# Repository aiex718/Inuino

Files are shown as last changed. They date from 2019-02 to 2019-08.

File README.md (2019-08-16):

# Inuino
An Arduino Uno compatible microcontroller dev board based on the ATmega644P / ATmega1284P, using official core inside Arduino IDE.

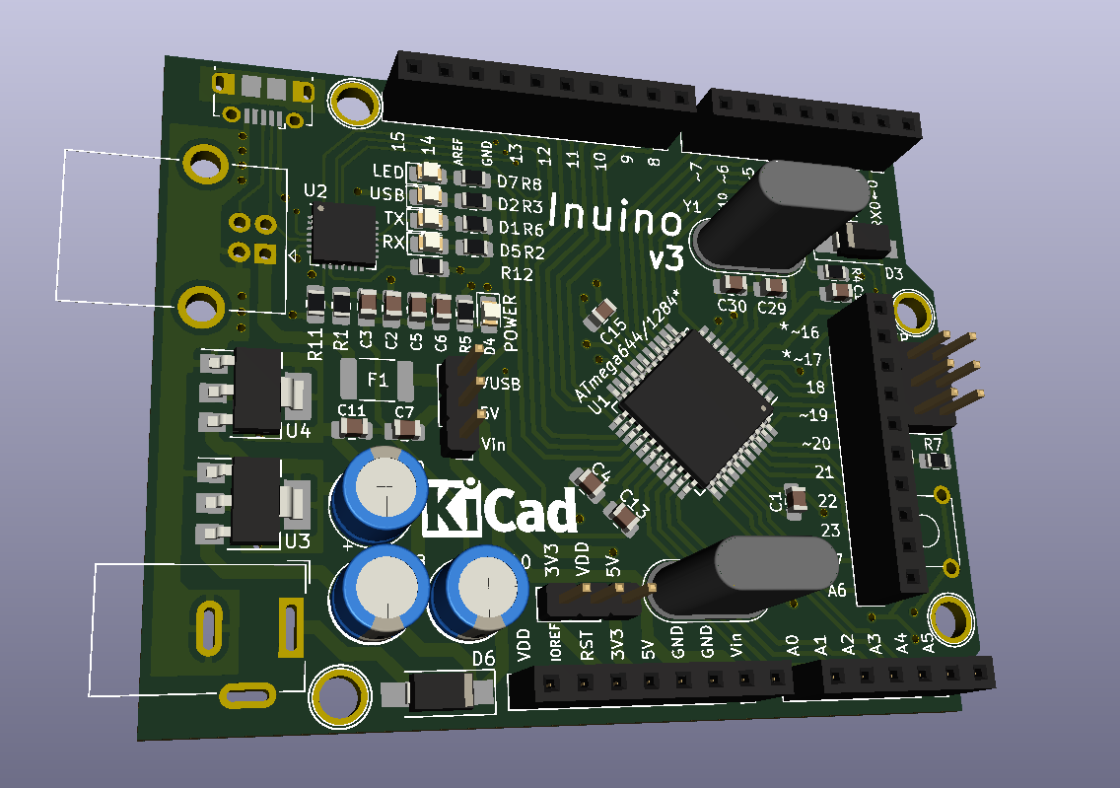
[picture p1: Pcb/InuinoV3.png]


# Usage
Add this link to boards manager

<https://raw.githubusercontent.com/aiex718/Inuino/master/Release/package_inuino_index.json>

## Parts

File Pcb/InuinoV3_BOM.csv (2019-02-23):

Id | Designator | Package | Quantity | Designation | Supplier and ref
1 | REF** | KiCad-Logo_5mm_SilkScreen | 1 | KiCad-Logo_5mm_SilkScreen
2 | J11 | PinHeader_1x03_P2.54mm_Vertical | 1 | VBUS_Jmp
3 | J10 | PinHeader_1x03_P2.54mm_Vertical | 1 | VDD_Jmp
4 | SW1 | SW_TH_Tactile_Omron_B3F-10xx | 1 | SW_DIP_x02
5 | C5,C1,C2,C4,C12,C13,C14,C15 | C_0805_2012Metric_Pad1.15x1.40mm_HandSolder | 8 | 100n
6 | U2 | QFN-28-1EP_5x5mm_P0.5mm_EP3.35x3.35mm_ThermalVias | 1 | CP2102N-A01-GQFN28
7 | R12,R2,R3,R5,R6,R7 | R_0805_2012Metric_Pad1.15x1.40mm_HandSolder | 6 | 1K
8 | R11 | R_0805_2012Metric_Pad1.15x1.40mm_HandSolder | 1 | 47.5K
9 | R10 | R_0805_2012Metric_Pad1.15x1.40mm_HandSolder | 1 | 1M
10 | D4 | LED_0805_2012Metric_Pad1.15x1.40mm_HandSolder | 1 | POWER
11 | D3 | D_SMA_Handsoldering | 1 | 1N5819
12 | J8 | PinSocket_1x10_P2.54mm_Vertical | 1 | IO3
13 | Y1 | Crystal_HC49-U_Vertical | 1 | 16M
14 | P5,P6,P7,P8 | Arduino_1pin | 4 | CONN_01X01
15 | C3,C6 | C_0805_2012Metric_Pad1.15x1.40mm_HandSolder | 2 | 4.7uF
16 | C7,C11 | C_0805_2012Metric_Pad1.15x1.40mm_HandSolder | 2 | 1uF
17 | C8,C9,C10 | CP_Radial_D6.3mm_P2.50mm | 3 | 47uF
18 | C29,C30 | C_0805_2012Metric_Pad1.15x1.40mm_HandSolder | 2 | 22p
19 | D1 | LED_0805_2012Metric_Pad1.15x1.40mm_HandSolder | 1 | RXD
20 | D2 | LED_0805_2012Metric_Pad1.15x1.40mm_HandSolder | 1 | USB_CONN
21 | D5 | LED_0805_2012Metric_Pad1.15x1.40mm_HandSolder | 1 | TXD
22 | D6 | D_SMA_Handsoldering | 1 | SM4007
23 | F1 | Fuse_1812_4532Metric_Pad1.30x3.40mm_HandSolder | 1 | 500mA
24 | J1 | PinHeader_2x03_P2.54mm_Vertical | 1 | ICSP
25 | J2 | USB_Micro-B_Molex-105017-0001 | 1 | USB_B_Micro
26 | J3 | PinSocket_1x10_P2.54mm_Vertical | 1 | IO1
27 | J4 | PinSocket_1x08_P2.54mm_Vertical | 1 | POWER_CONN
28 | J5 | USB_B_OST_USB-B1HSxx_Horizontal | 1 | USB_B
29 | J6 | PinSocket_1x08_P2.54mm_Vertical | 1 | IO0
30 | J7 | PinSocket_1x06_P2.54mm_Vertical | 1 | IO2
31 | J9 | BarrelJack_Wuerth_6941xx301002 | 1 | Jack-DC
32 | R1 | R_0805_2012Metric_Pad1.15x1.40mm_HandSolder | 1 | 22.1K
33 | R4,R8 | R_0805_2012Metric_Pad1.15x1.40mm_HandSolder | 2 | 300
34 | U3 | SOT-223-3_TabPin2 | 1 | AMS1117-5.0
35 | U4 | SOT-223-3_TabPin2 | 1 | AMS1117-3.3
36 | Y2 | Crystal_HC49-U_Vertical | 1 | 8M
37 | U1 | LQFP-44_10x10mm_P0.8mm | 1 | IC--ATMEGA644PA-AU
38 | D7 | LED_0805_2012Metric_Pad1.15x1.40mm_HandSolder | 1 | LED

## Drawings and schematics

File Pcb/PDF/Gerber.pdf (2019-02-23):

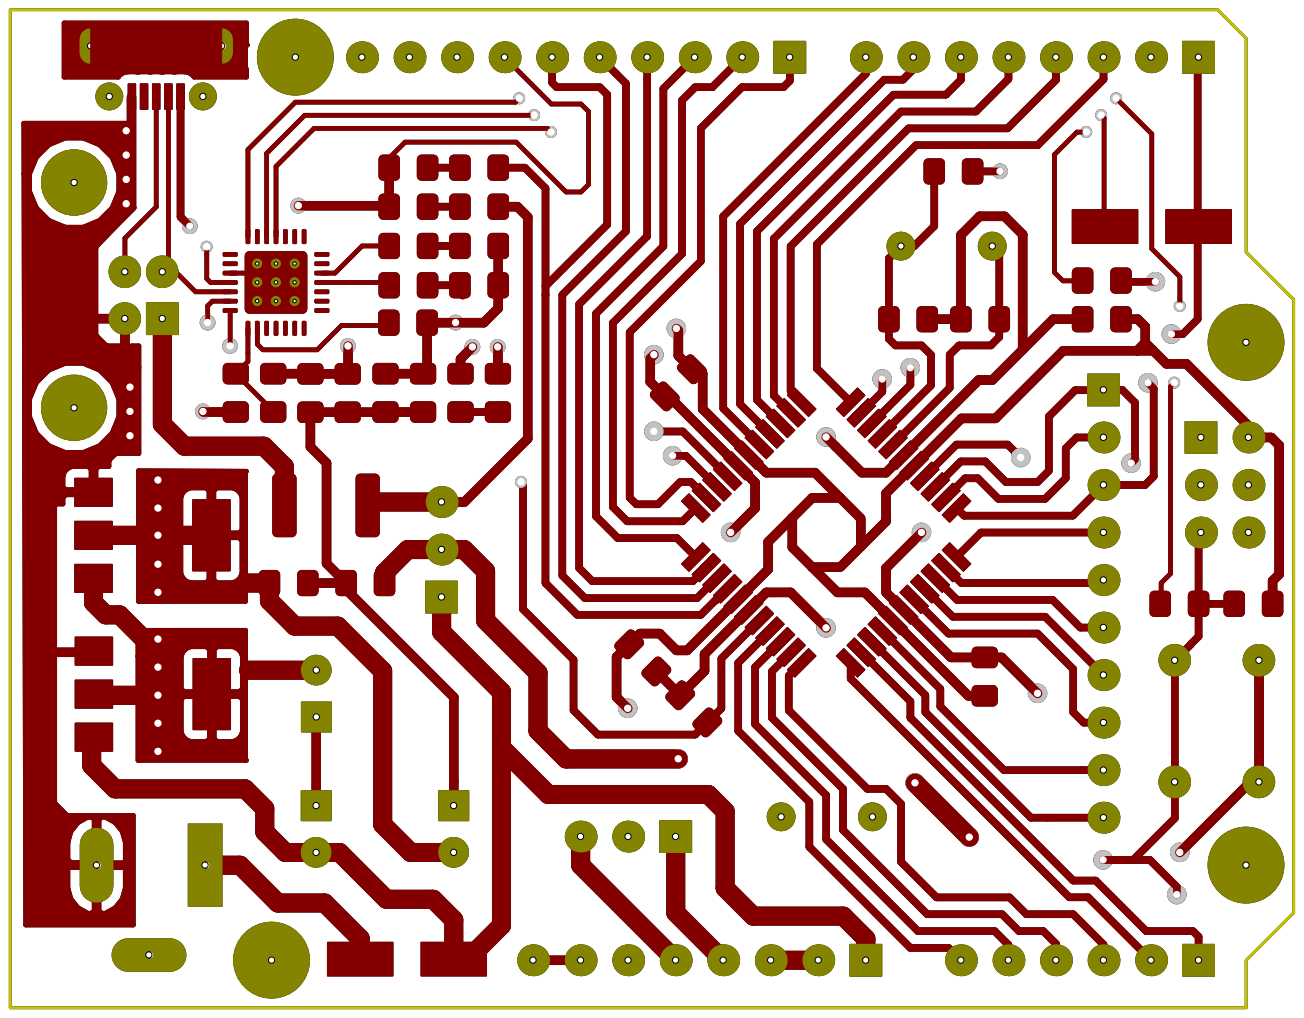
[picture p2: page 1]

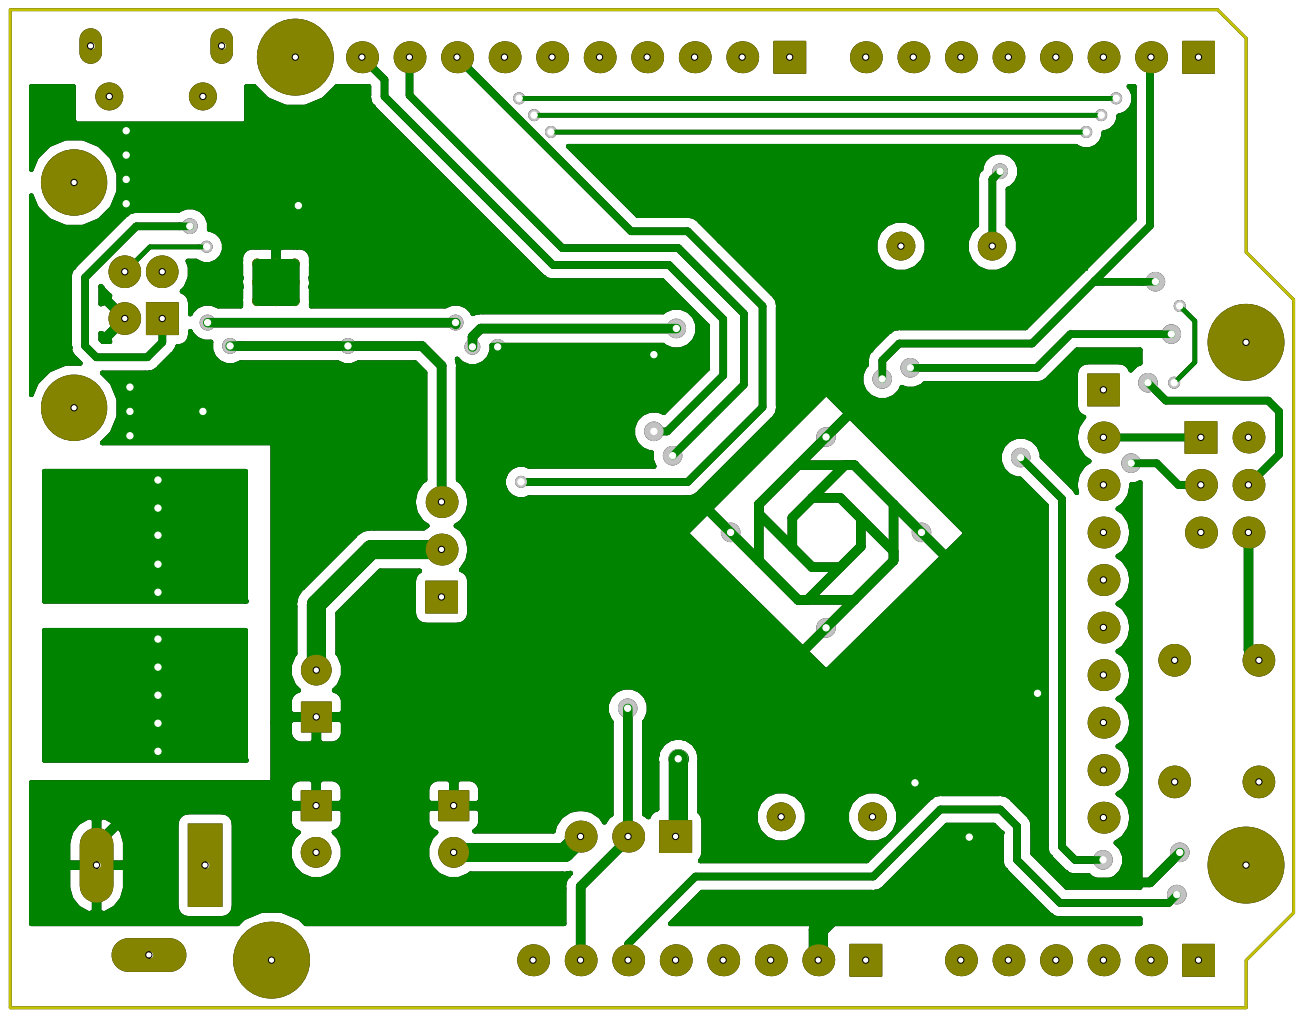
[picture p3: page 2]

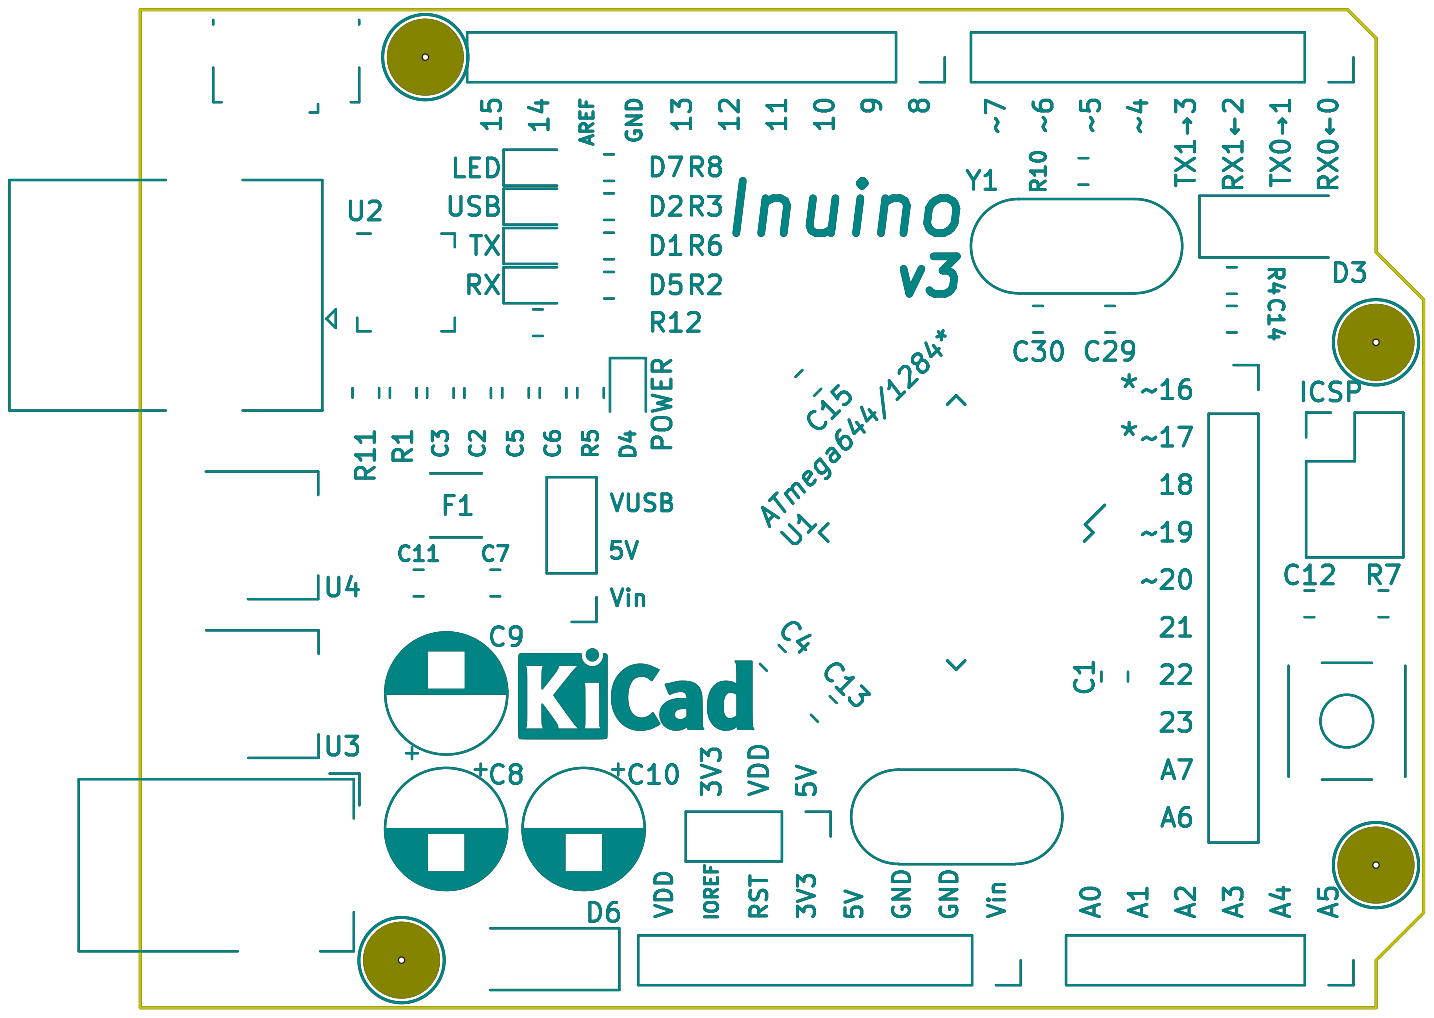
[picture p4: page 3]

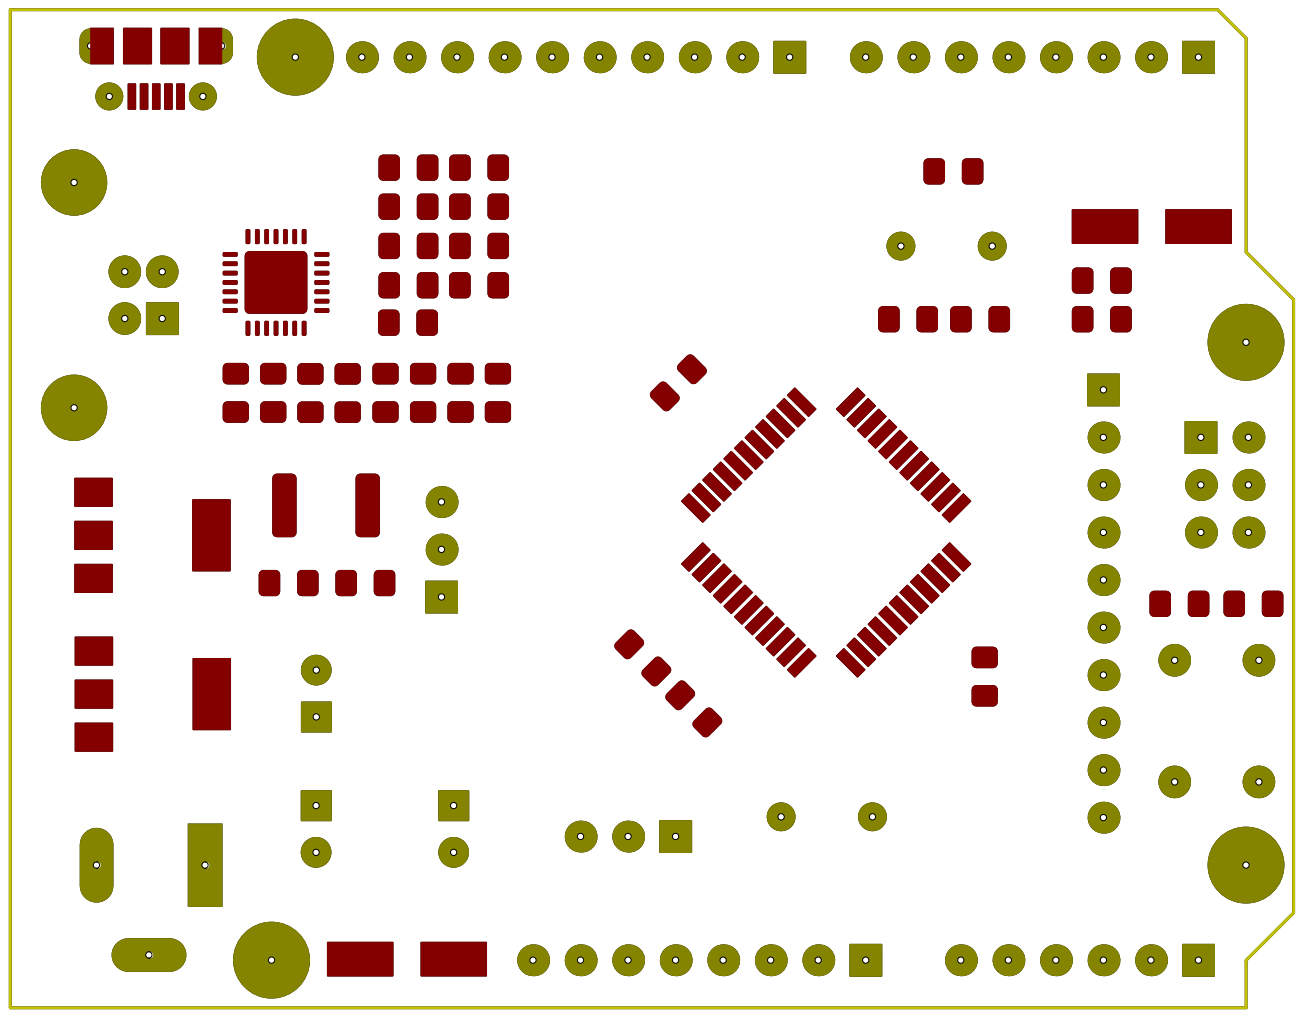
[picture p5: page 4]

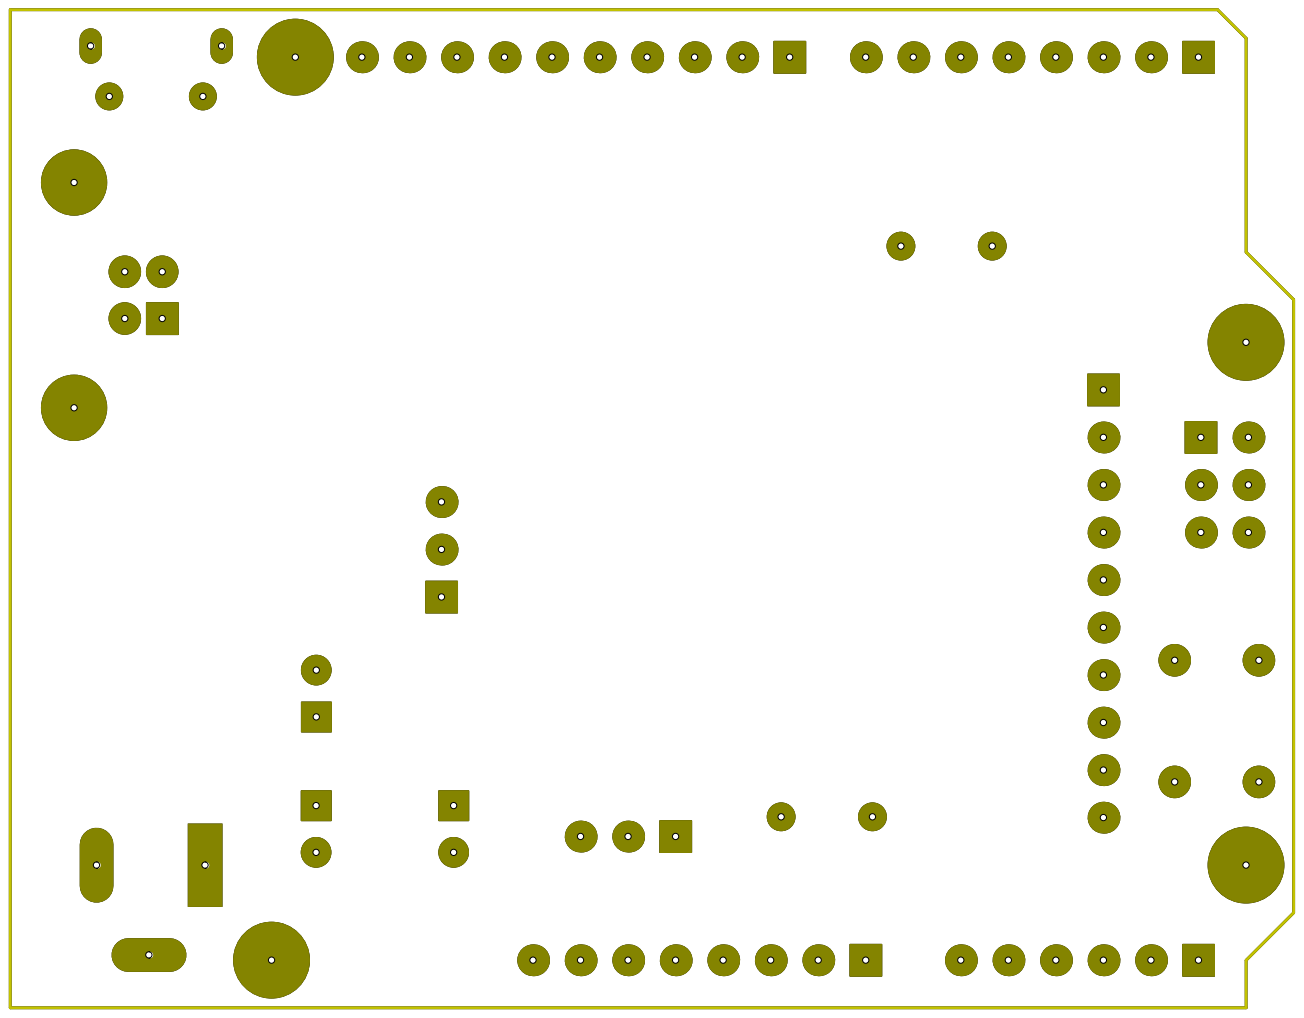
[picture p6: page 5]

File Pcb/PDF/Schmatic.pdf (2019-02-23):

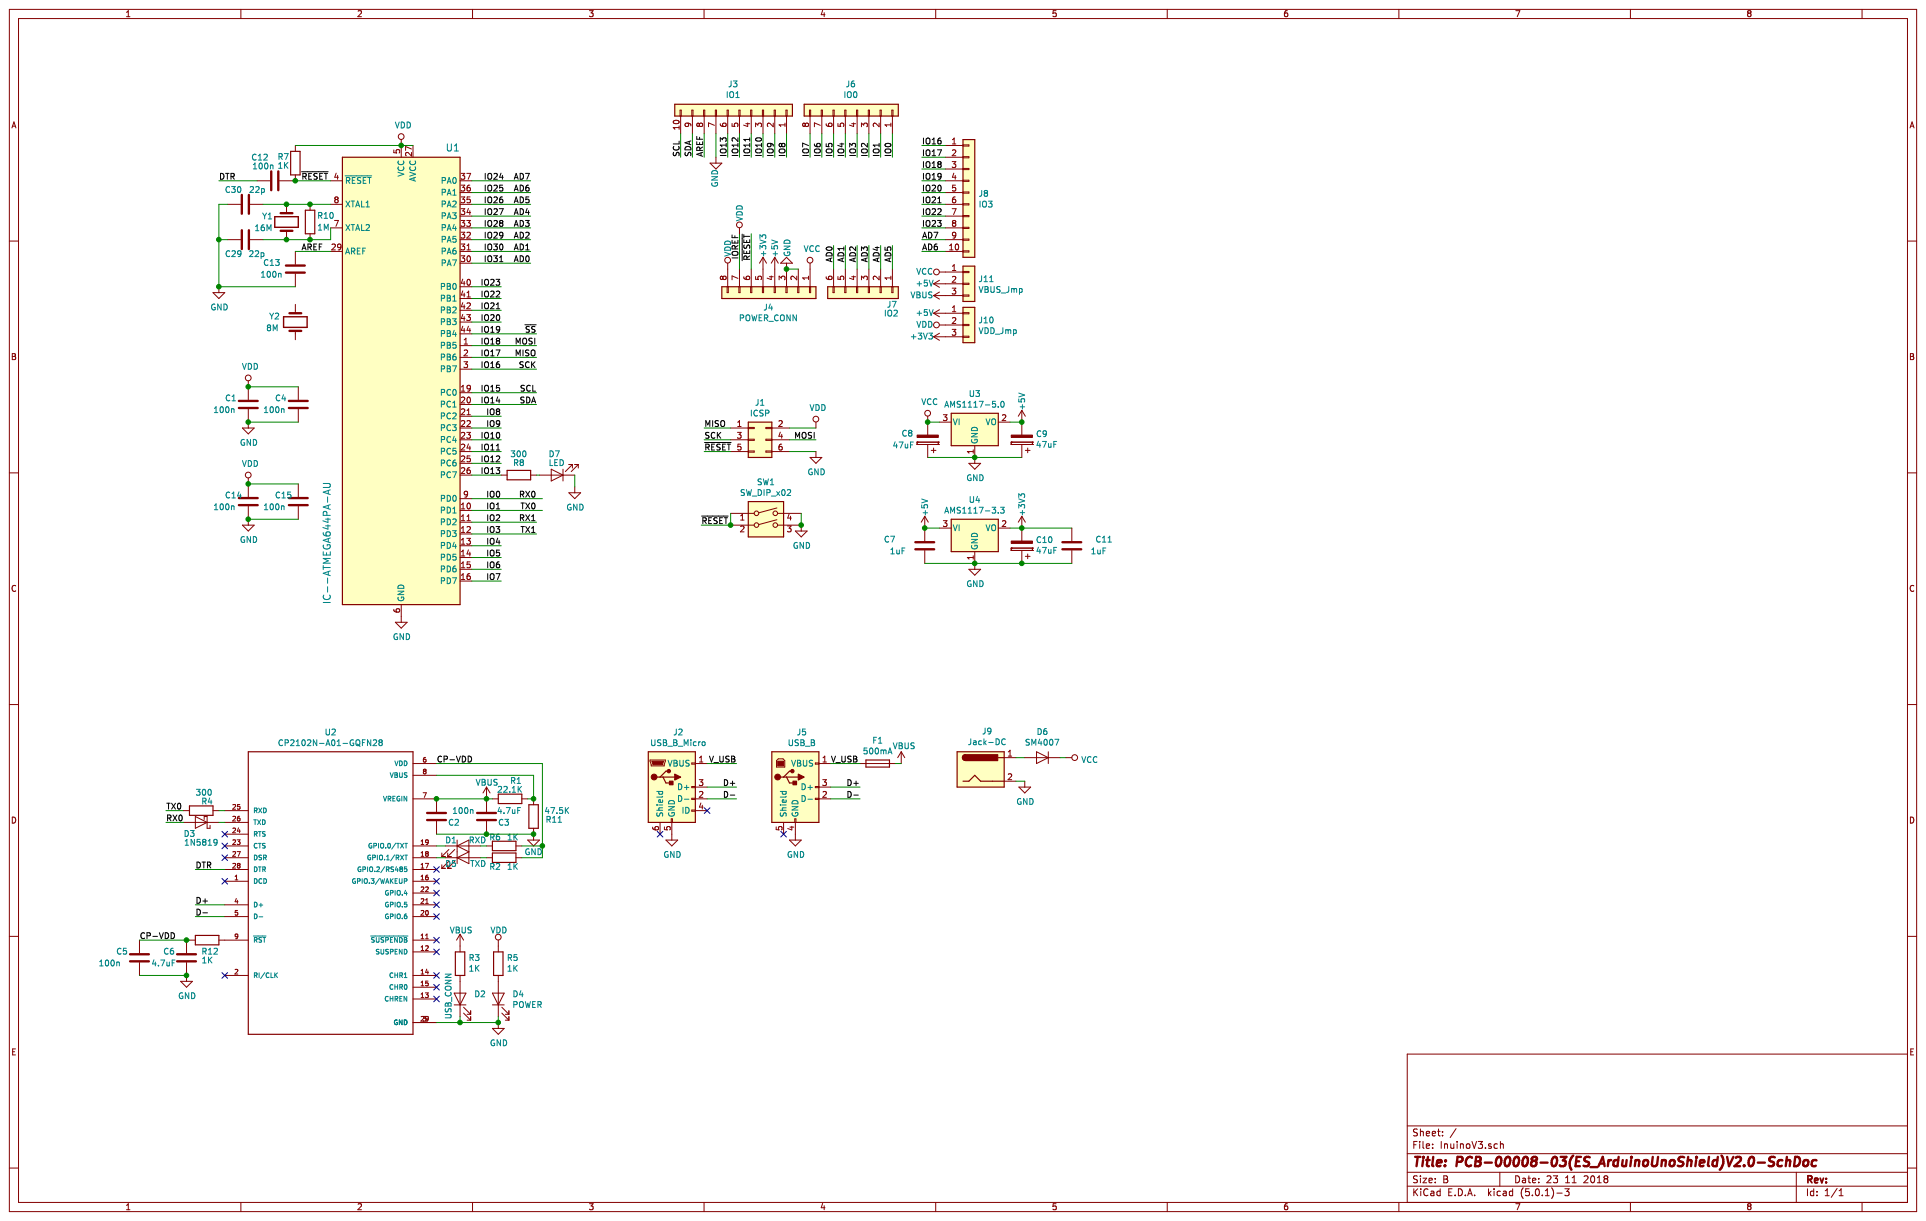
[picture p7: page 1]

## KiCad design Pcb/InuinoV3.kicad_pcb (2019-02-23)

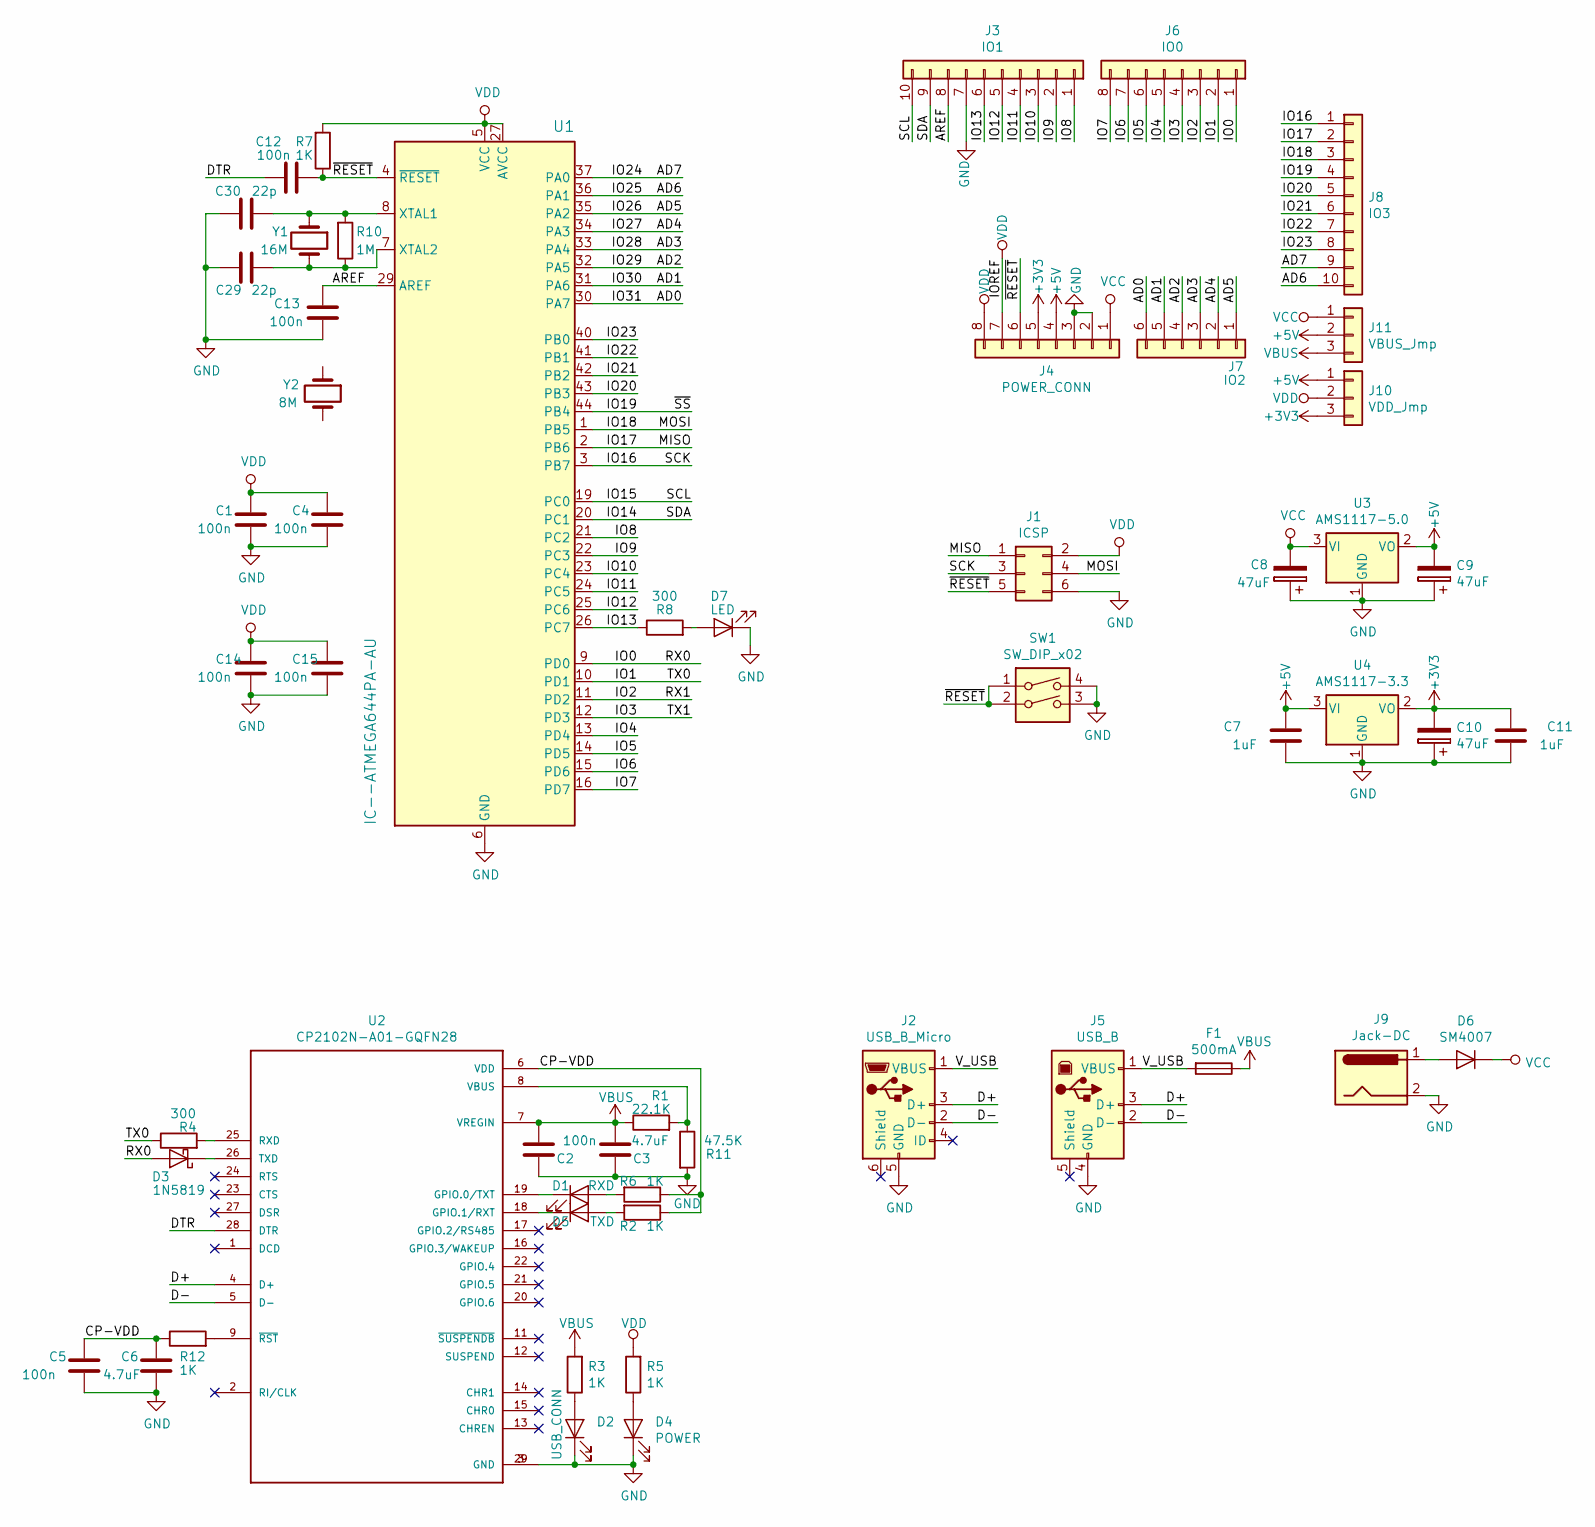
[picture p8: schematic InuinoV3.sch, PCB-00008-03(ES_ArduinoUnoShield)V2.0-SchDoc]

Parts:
C1, C2, C4, C5, C12, C13, C14, C15: 100n; C_0805_2012Metric_Pad1.15x1.40mm_HandSolder
C3, C6: 4.7uF; C_0805_2012Metric_Pad1.15x1.40mm_HandSolder
C7, C11: 1uF; C_0805_2012Metric_Pad1.15x1.40mm_HandSolder
C8, C9, C10: 47uF; CP_Radial_D6.3mm_P2.50mm
C29, C30: 22p; C_0805_2012Metric_Pad1.15x1.40mm_HandSolder
D1: RXD; LED_0805_2012Metric_Pad1.15x1.40mm_HandSolder
D2: USB_CONN; LED_0805_2012Metric_Pad1.15x1.40mm_HandSolder
D3: 1N5819; D_SMA_Handsoldering
D4: POWER; LED_0805_2012Metric_Pad1.15x1.40mm_HandSolder
D5: TXD; LED_0805_2012Metric_Pad1.15x1.40mm_HandSolder
D6: SM4007; D_SMA_Handsoldering
D7: LED; LED_0805_2012Metric_Pad1.15x1.40mm_HandSolder
F1: 500mA; Fuse_1812_4532Metric_Pad1.30x3.40mm_HandSolder
J1: ICSP; PinHeader_2x03_P2.54mm_Vertical
J2: USB_B_Micro; USB_Micro-B_Molex-105017-0001
J3: IO1; PinSocket_1x10_P2.54mm_Vertical
J4: POWER_CONN; PinSocket_1x08_P2.54mm_Vertical
J5: USB_B; USB_B_OST_USB-B1HSxx_Horizontal
J6: IO0; PinSocket_1x08_P2.54mm_Vertical
J7: IO2; PinSocket_1x06_P2.54mm_Vertical
J8: IO3; PinSocket_1x10_P2.54mm_Vertical
J9: Jack-DC; BarrelJack_Wuerth_6941xx301002
J10: VDD_Jmp; PinHeader_1x03_P2.54mm_Vertical
J11: VBUS_Jmp; PinHeader_1x03_P2.54mm_Vertical
R1: 22.1K; R_0805_2012Metric_Pad1.15x1.40mm_HandSolder
R2, R3, R5, R6, R7, R12: 1K; R_0805_2012Metric_Pad1.15x1.40mm_HandSolder
R4, R8: 300; R_0805_2012Metric_Pad1.15x1.40mm_HandSolder
R10: 1M; R_0805_2012Metric_Pad1.15x1.40mm_HandSolder
R11: 47.5K; R_0805_2012Metric_Pad1.15x1.40mm_HandSolder
SW1: SW_DIP_x02; SW_TH_Tactile_Omron_B3F-10xx
U1: IC--ATMEGA644PA-AU; LQFP-44_10x10mm_P0.8mm
U2: CP2102N-A01-GQFN28; QFN-28-1EP_5x5mm_P0.5mm_EP3.35x3.35mm_ThermalVias
U3: AMS1117-5.0; SOT-223-3_TabPin2
U4: AMS1117-3.3; SOT-223-3_TabPin2
Y1: 16M; Crystal_HC49-U_Vertical
Y2: 8M; Crystal_HC49-U_Vertical

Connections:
+3V3: C10.2, C11.2, J4.5, J10.3, U4.2 (VO)
+5V: C7.2, C9.2, J4.4, J10.1, J11.2, U3.2 (VO), U4.3 (VI)
/AD0: J7.6, U1.30 (PA7)
/AD1: J7.5, U1.31 (PA6)
/AD2: J7.4, U1.32 (PA5)
/AD3: J7.3, U1.33 (PA4)
/AD4: J7.2, U1.34 (PA3)
/AD5: J7.1, U1.35 (PA2)
/AD6: J8.10, U1.36 (PA1)
/AD7: J8.9, U1.37 (PA0)
/AREF: C13.2, J3.8, U1.29 (AREF)
/CP-VDD: C5.2, C6.2, R2.1, R6.1, R12.1, U2.6 (VDD)
/D+: J2.3 (D+), J5.3 (D+), U2.4 (D+)
/D-: J2.2 (D-), J5.2 (D-), U2.5 (D-)
/DTR: C12.2, U2.28 (DTR)
/IO0: D3.2 (A), J6.1, U1.9 (PD0)
/IO1: J6.2, R4.1, U1.10 (PD1)
/IO2: J6.3, U1.11 (PD2)
/IO3: J6.4, U1.12 (PD3)
/IO4: J6.5, U1.13 (PD4)
/IO5: J6.6, U1.14 (PD5)
/IO6: J6.7, U1.15 (PD6)
/IO7: J6.8, U1.16 (PD7)
/IO8: J3.1, U1.21 (PC2)
/IO9: J3.2, U1.22 (PC3)
/IO10: J3.3, U1.23 (PC4)
/IO11: J3.4, U1.24 (PC5)
/IO12: J3.5, U1.25 (PC6)
/IO13: J3.6, R8.1, U1.26 (PC7)
/IO14: J3.9, U1.20 (PC1)
/IO15: J3.10, U1.19 (PC0)
/IO16: J1.3, J8.1, U1.3 (PB7)
/IO17: J1.1, J8.2, U1.2 (PB6)
/IO18: J1.4, J8.3, U1.1 (PB5)
/IO19: J8.4, U1.44 (PB4)
/IO20: J8.5, U1.43 (PB3)
/IO21: J8.6, U1.42 (PB2)
/IO22: J8.7, U1.41 (PB1)
/IO23: J8.8, U1.40 (PB0)
/V_USB: F1.2, J2.1 (VBUS), J5.1 (VBUS)
/~RESET~: C12.1, J1.5, J4.6, R7.1, SW1.1, SW1.2, U1.4 (~RESET)
GND: C1.1, C2.2, C3.2, C4.1, C5.1, C6.1, C7.1, C8.1, C9.1, C10.1, C11.1, C13.1, C14.1, C15.1, C29.1, C30.2, D2.1 (K), D4.1 (K), D7.1 (K), J1.6, J2.5 (GND), J3.7, J4.2, J4.3, J5.4 (GND), J9.2, R11.2, SW1.3, SW1.4, U1.6 (GND), U1.18 (GND), U1.28 (GND), U1.39 (GND), U2.3 (GND), U2.29 (GND), U3.1 (GND), U4.1 (GND)
unnamed: C29.2, R10.1, U1.7 (XTAL2), Y1.2
unnamed: C30.1, R10.2, U1.8 (XTAL1), Y1.1
unnamed: D1.1 (K), U2.19 (GPIO.0/TXT)
unnamed: D1.2 (A), R6.2
unnamed: D2.2 (A), R3.1
unnamed: D3.1 (K), U2.26 (TXD)
unnamed: D4.2 (A), R5.1
unnamed: D5.1 (K), U2.18 (GPIO.1/RXT)
unnamed: D5.2 (A), R2.2
unnamed: D6.2 (A), J9.1
unnamed: D7.2 (A), R8.2
unnamed: R1.2, R11.1, U2.8 (VBUS)
unnamed: R4.2, U2.25 (RXD)
unnamed: R12.2, U2.9 (~RST~)
VBUS: C2.1, C3.1, F1.1, J11.3, R1.1, R3.2, U2.7 (VREGIN)
VCC: C8.2, D6.1 (K), J4.1, J11.1, U3.3 (VI)
VDD: C1.2, C4.2, C14.2, C15.2, J1.2, J4.7, J4.8, J10.2, R5.2, R7.2, U1.5 (VCC), U1.17 (VCC), U1.27 (AVCC), U1.38 (VCC)

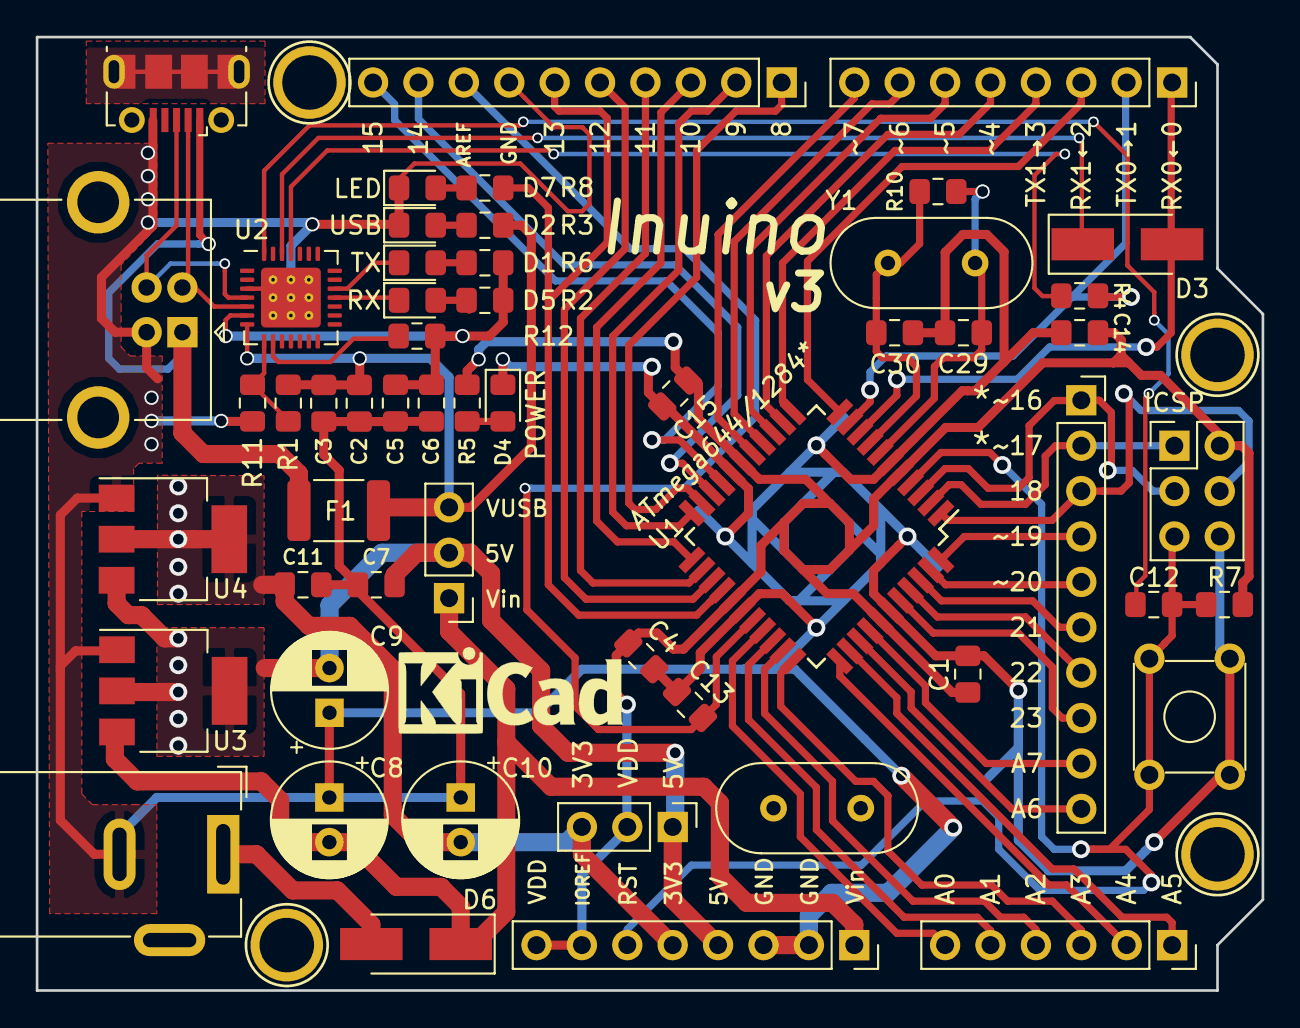
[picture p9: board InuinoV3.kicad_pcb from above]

Board: 2 copper layers, 68.6 x 53.3 mm, 58 parts (0 on the bottom side), 59 nets.

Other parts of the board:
P5, P6, P7, P8: CONN_01X01; Arduino_1pin

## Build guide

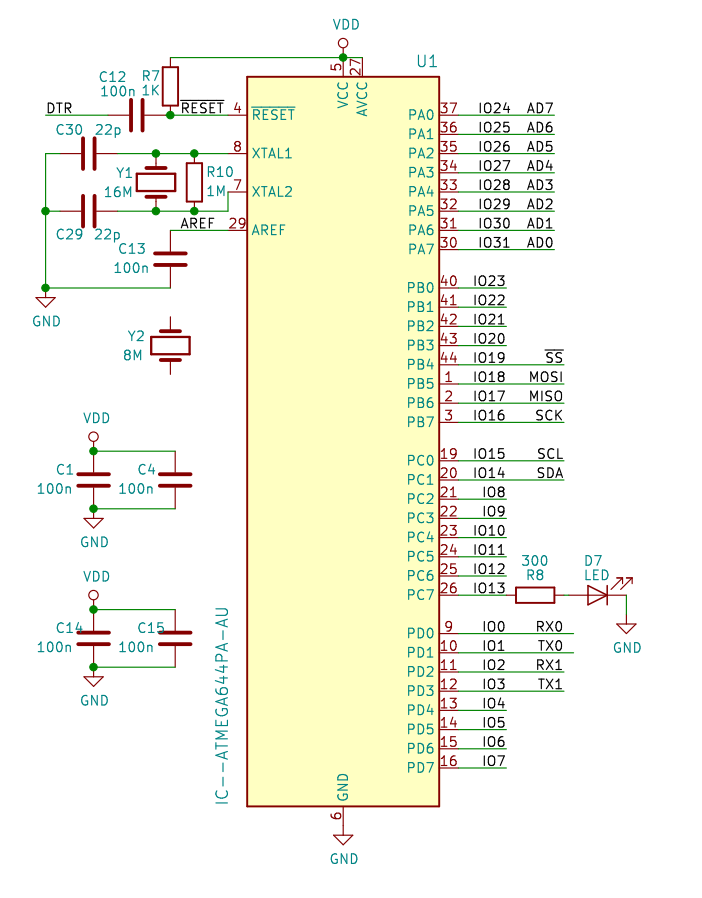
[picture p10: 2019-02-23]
Pcb/Wiring.png

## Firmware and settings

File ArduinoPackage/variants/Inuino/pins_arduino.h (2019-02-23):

/*
  pins_arduino.h - Pin definition functions for Arduino
  Part of Arduino - http://www.arduino.cc/

  Copyright (c) 2007 David A. Mellis

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
  You should have received a copy of the GNU Lesser General
  Public License along with this library; if not, write to the
  Free Software Foundation, Inc., 59 Temple Place, Suite 330,
  Boston, MA  02111-1307  USA
*/

#ifndef Pins_Arduino_h
#define Pins_Arduino_h

#include <avr/pgmspace.h>

#define NUM_DIGITAL_PINS            32
#define NUM_ANALOG_INPUTS           8

//Set SPI and I2C to digital pins
static const uint8_t SS   = 19;
static const uint8_t MOSI = 18;
static const uint8_t MISO = 17;
static const uint8_t SCK  = 16;

static const uint8_t SDA = 14;
static const uint8_t SCL = 15;

//Set LED_BUILTIN to digital pins
#define LED_BUILTIN 13

//Set analog pins to digital pins
static const uint8_t A0 = 31;
static const uint8_t A1 = 30;
static const uint8_t A2 = 29;
static const uint8_t A3 = 28;
static const uint8_t A4 = 27;
static const uint8_t A5 = 26;
static const uint8_t A6 = 25;
static const uint8_t A7 = 24;


//Set analog pins to digital pins, A?=D?
#define analogInputToDigitalPin(p)  ((p < NUM_ANALOG_INPUTS) ? 31 - (p) : -1)



//Set which digital pins has pwm(timer)
#if defined(__AVR_ATmega644P__)
#define digitalPinHasPWM(p)         ((p) == 4 || (p) == 5 || (p) == 6 || (p) == 7 || (p) == 19 || (p) == 20)
#elif defined(__AVR_ATmega1284P__)
#define digitalPinHasPWM(p)         ((p) == 4 || (p) == 5 || (p) == 6 || (p) == 7 || (p) == 16 || (p) == 17 || (p) == 19 || (p) == 20)
#endif


// Set digitalPin To PCICR
// p.s. All digitalPin on 644p/1284p has PCICR
#define digitalPinToPCICR(p)    (((p) >= 0 && (p) < NUM_DIGITAL_PINS) ? (&PCICR) : ((uint8_t *)0)) 

// Set digitalPin To PCICR bit
// PortD = 3,PortC = 2,PortB = 1,PortA = 0
#define digitalPinToPCICRbit(p) (((p) <= 7) ? 3 : (((p) <= 15) ? 2 : (((p) <= 23) ? 1 : 0)))

// Set digitalPin To PCMSK 
// PortD = &PCMSK3,PortC = &PCMSK2,PortB = &PCMSK1,PortA = &PCMSK0
#define digitalPinToPCMSK(p)    (((p) <= 7) ? (&PCMSK3) : (((p) <= 15) ? (&PCMSK2) : (((p) <= 23) ? (&PCMSK1) : (&PCMSK0))))  


// Set digitalPin To PCMSK bit
// Relative to digital_pin_to_port_PGM and digital_pin_to_bit_mask_PGM
#define digitalPinToPCMSKbit(p) (((p) <= 7) ? ((p) % 8) : (((p) <= 13) ? ( (p) - 6 ) : (((p) <= 15) ? ( 15 - (p)) : (((p)<=23)?( 23 - (p) ):((p) % 8))))) 

//Set which digital pins has interrupt
#define digitalPinToInterrupt(p)  ((p) == 2 ? 0 : ((p) == 3 ? 1 : ((p) == 21 ? 2 : NOT_AN_INTERRUPT)))


#ifdef ARDUINO_MAIN


// these arrays map port names (e.g. port B) to the
// appropriate addresses for various functions (e.g. reading
// and writing)
const uint16_t PROGMEM port_to_mode_PGM[] = {
	NOT_A_PORT,
	(uint16_t) &DDRA,
	(uint16_t) &DDRB,
	(uint16_t) &DDRC,
	(uint16_t) &DDRD,
};

const uint16_t PROGMEM port_to_output_PGM[] = {
	NOT_A_PORT,
	(uint16_t) &PORTA,
	(uint16_t) &PORTB,
	(uint16_t) &PORTC,
	(uint16_t) &PORTD,
};

const uint16_t PROGMEM port_to_input_PGM[] = {
	NOT_A_PORT,
	(uint16_t) &PINA,
	(uint16_t) &PINB,
	(uint16_t) &PINC,
	(uint16_t) &PIND,
};

const uint8_t PROGMEM digital_pin_to_port_PGM[] = {
	PD, //D0
	PD,
	PD,
	PD,
	PD,
	PD,
	PD,
	PD,
	PC, //D8
	PC,
	PC,
	PC,
	PC,
	PC,
	PC, 
	PC,
	PB, //D16
	PB,
	PB,
	PB,
	PB,
	PB,
	PB,
	PB,
	PA, //D24,AD7
	PA,
	PA,
	PA,
	PA,
	PA,
	PA,
	PA
};

const uint8_t PROGMEM digital_pin_to_bit_mask_PGM[] = {
	_BV(0), // D0 , port D0
	_BV(1), // D1 , port D1
	_BV(2), // D2 , port D2
	_BV(3), // D3 , port D3
	_BV(4), // D4 , port D4
	_BV(5), // D5 , port D5
	_BV(6), // D6 , port D6
	_BV(7), // D7 , port D7
	_BV(2), // D8 , port C2
	_BV(3), // D9 , port C3
	_BV(4), // D10, port C4
	_BV(5), // D11, port C5
	_BV(6), // D12, port C6
	_BV(7), // D13, port C7
	_BV(1), // D14, port C1
	_BV(0), // D15, port C0
	_BV(7), // D16, port B7
	_BV(6), // D17, port B6
	_BV(5), // D18, port B5
	_BV(4), // D19, port B4
	_BV(3), // D20, port B3
	_BV(2), // D21, port B2
	_BV(1), // D22, port B1
	_BV(0), // D23, port B0
	_BV(0), // D24 AD7, port A0
	_BV(1), // D25 AD6, port A1
	_BV(2), // D26 AD5, port A2
	_BV(3), // D27 AD4, port A3
	_BV(4), // D28 AD3, port A4
	_BV(5), // D29 AD2, port A5
	_BV(6), // D30 AD1, port A6
	_BV(7)  // D31 AD0, port A7
};
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
